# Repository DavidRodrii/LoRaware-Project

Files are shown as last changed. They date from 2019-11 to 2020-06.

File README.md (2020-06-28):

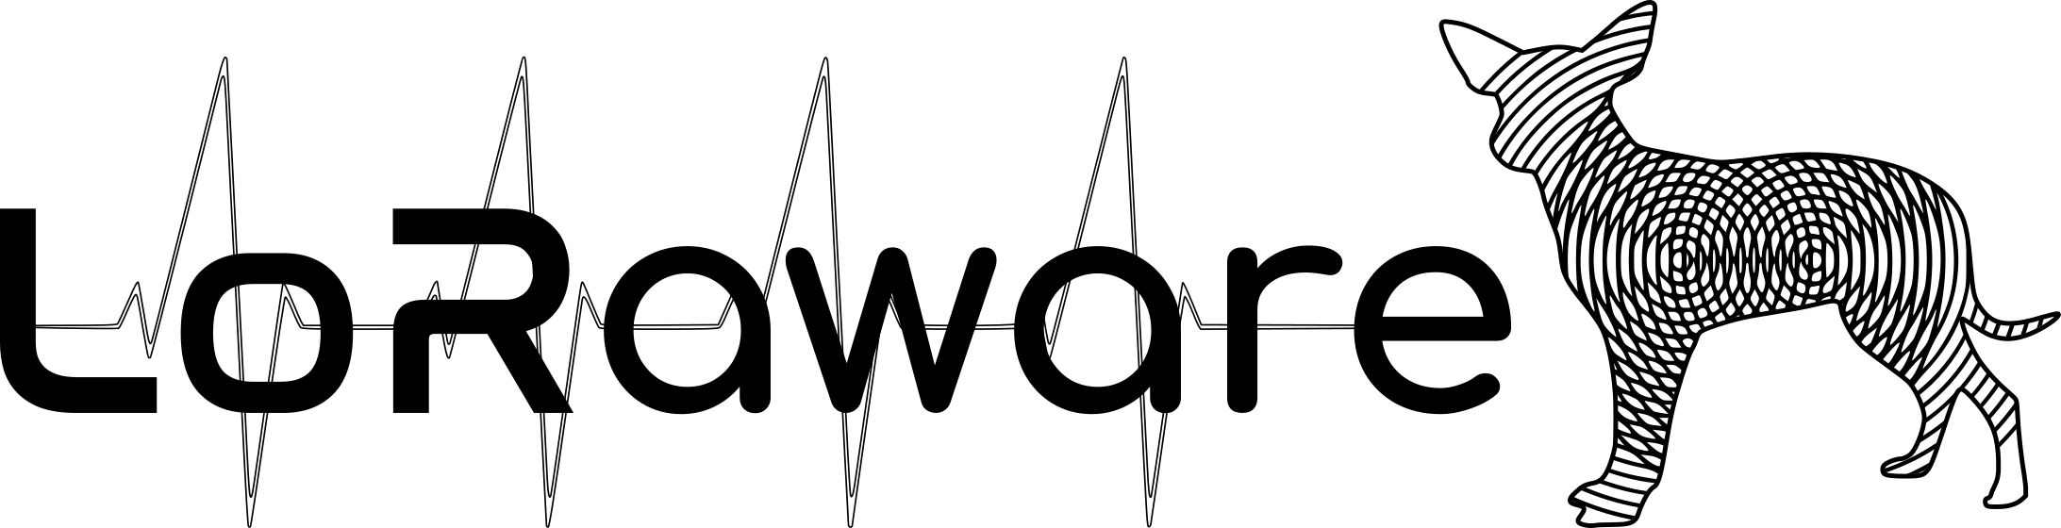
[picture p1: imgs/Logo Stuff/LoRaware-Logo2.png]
The LoRaware Project


### What is it?

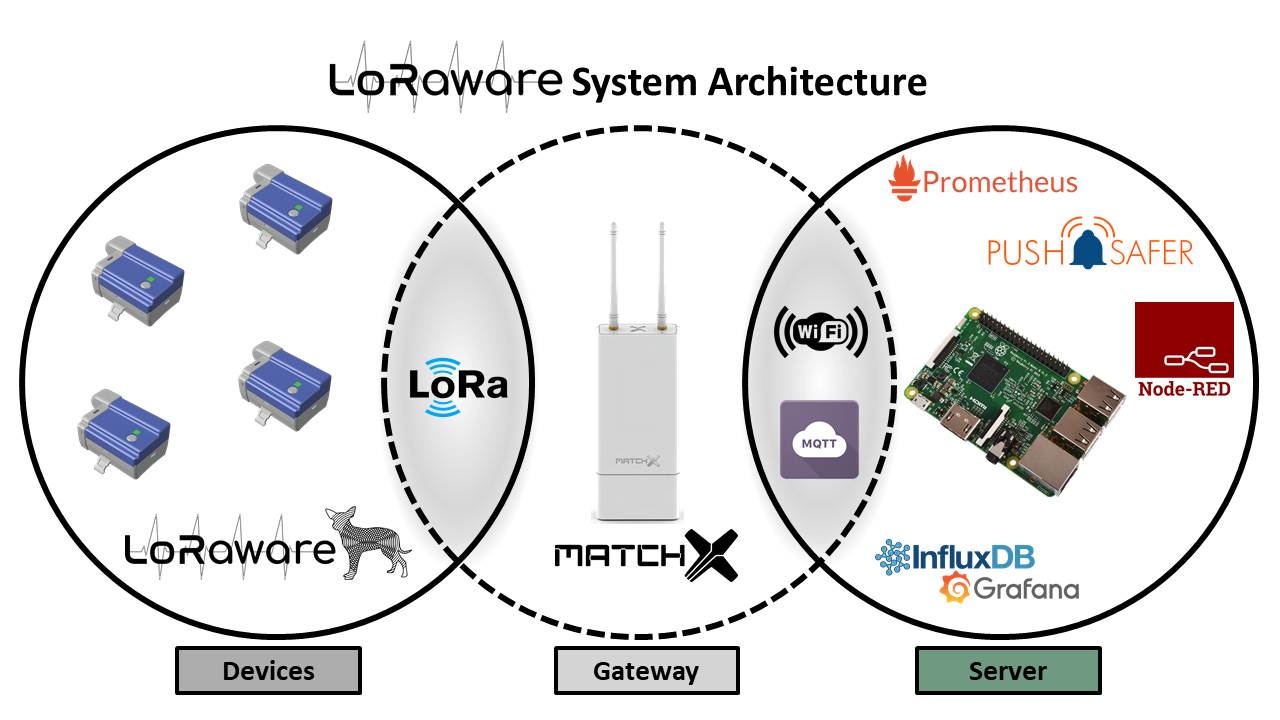
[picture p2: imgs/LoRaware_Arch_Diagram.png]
The LoRaware System Architecture


This capstone project represents the culmination of the Master of Science in Electrical Engineering with specialization in Wireless Communication program at National University. This project focused on the research and development of a wireless sensor network for use in the medical field pertaining to out-patient monitoring. The developed system's first deployment consisted of four wireless biometric devices transmitting communications over a Long-Range Wide Area Network (LoRaWAN). The observed biometric data was obtained by a combination of sampling, reading analog and digital voltage values, and conversions performed by each device’s processor, then transmitted to a centralized LoRaWAN Gateway, which was then parsed and forwarded to a network server via TCP/IP Stack to be stored and displayed by hosted services and applications; forming a lightweight and functional management platform. The project team developed and successfully tested the proposed LoRaware system throughout the course of a three-month duration.

Assembly of Snap-Fit Enclosure Shells

Enclosure Assembly

The sensor sets are portable and wrist-wearable and include sensors for biometric measurements, a ESP32 MCU, a Lithium Polymer battery, LoRa RF Modulation chipset and external antenna for data transmissions. All components fit in a low-profile enclosure.

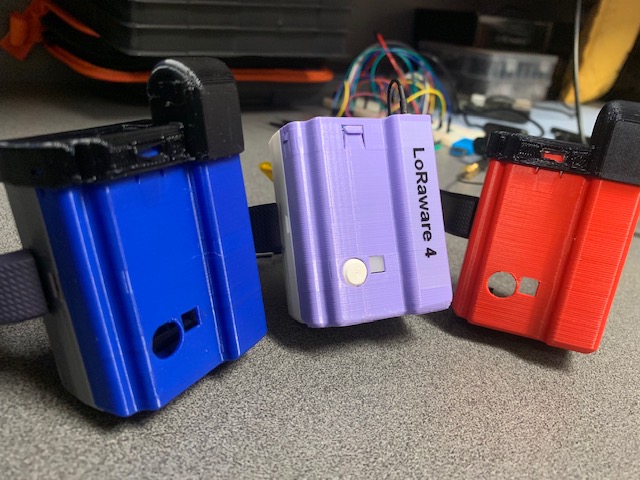
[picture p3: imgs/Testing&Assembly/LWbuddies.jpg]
Hmmmm...


<!--
Cutaway View
<img src="https://raw.githubusercontent.com/DavidRodrii/LoRaware-Project/master/imgs/lware-cutaway1.png" alt="Cutaway View" />
-->

Rendering of Full Assembly
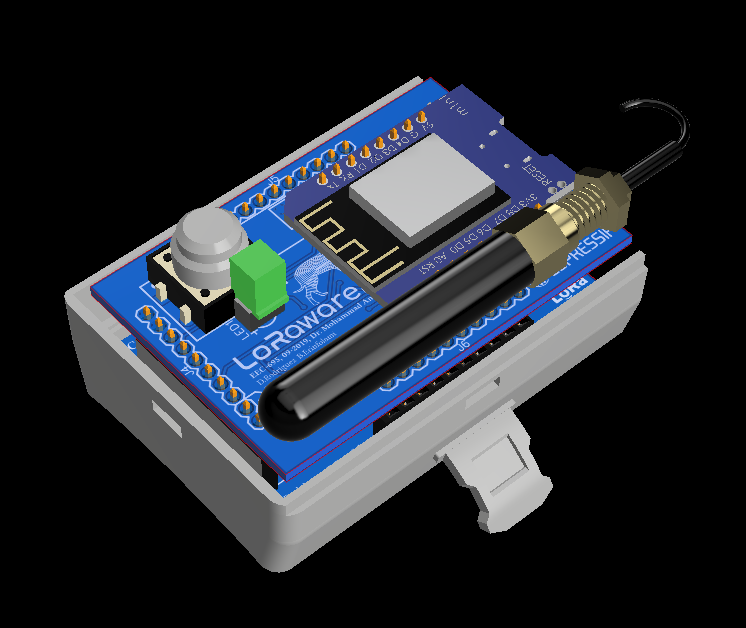
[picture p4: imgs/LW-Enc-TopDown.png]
Fully Assembly, wit da Top Down


### Use-case

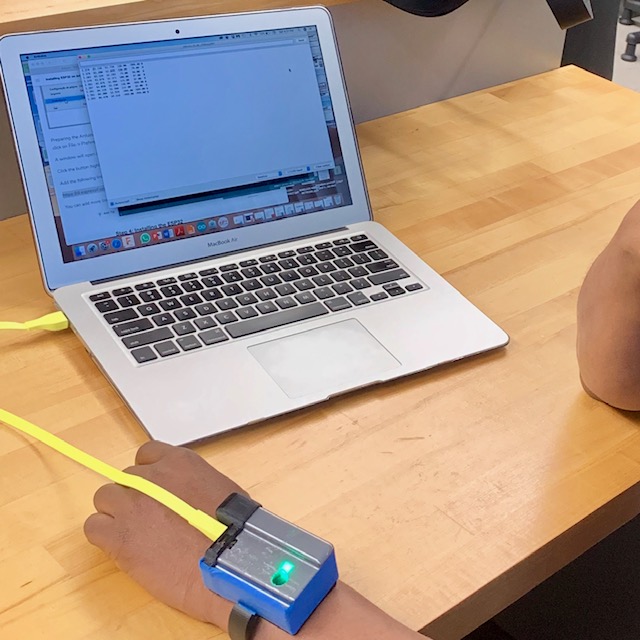
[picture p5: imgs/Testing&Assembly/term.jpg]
Debugging LoRaware Device


Biometric Monitoring

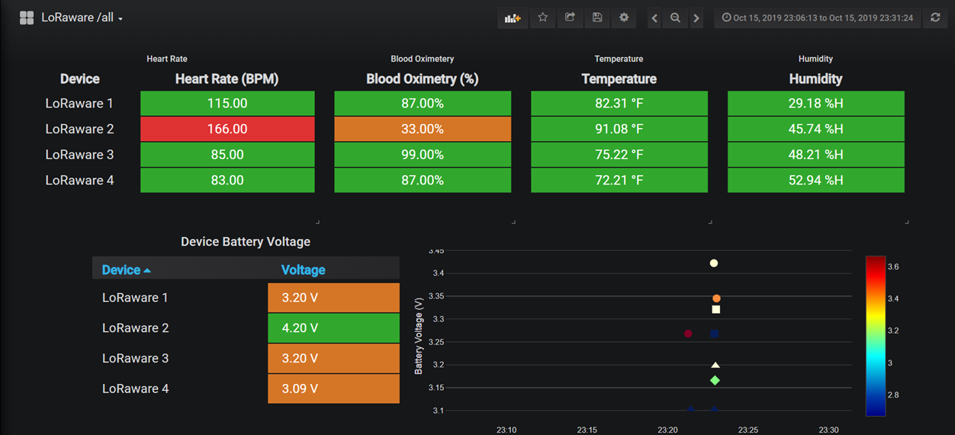
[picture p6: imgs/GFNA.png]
Monitoring Biometrics


<!-- Signal-to-Noise Ratio of Received LoRaWAN Packets
<img src="https://raw.githubusercontent.com/DavidRodrii/LoRaware-Project/master/imgs/LoRa_SNR.png" alt="SNR" />
-->

MQTT Data Flow Management topology in Node-Red
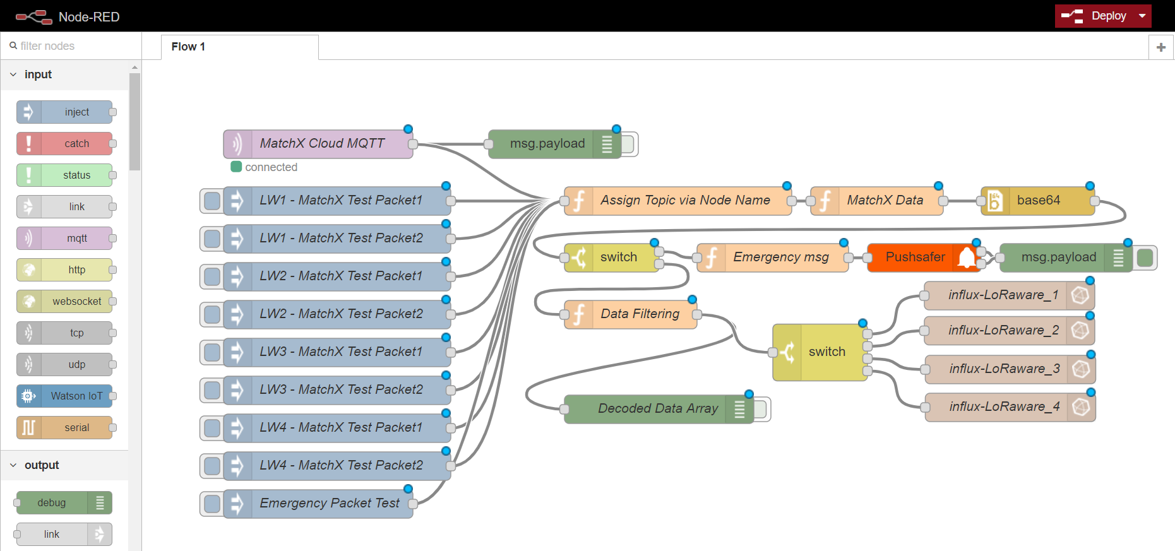
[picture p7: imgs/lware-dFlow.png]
Flow Control


LoRaware Automated Notification System with Pushsafer API
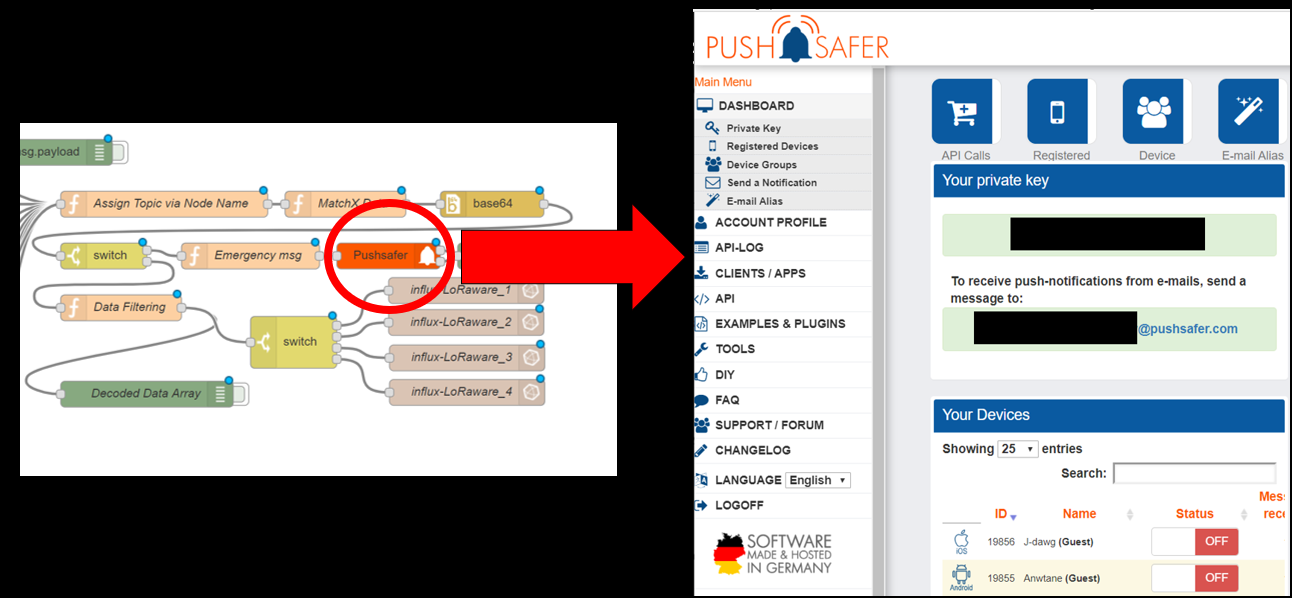
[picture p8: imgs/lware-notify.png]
Notify System


### Development

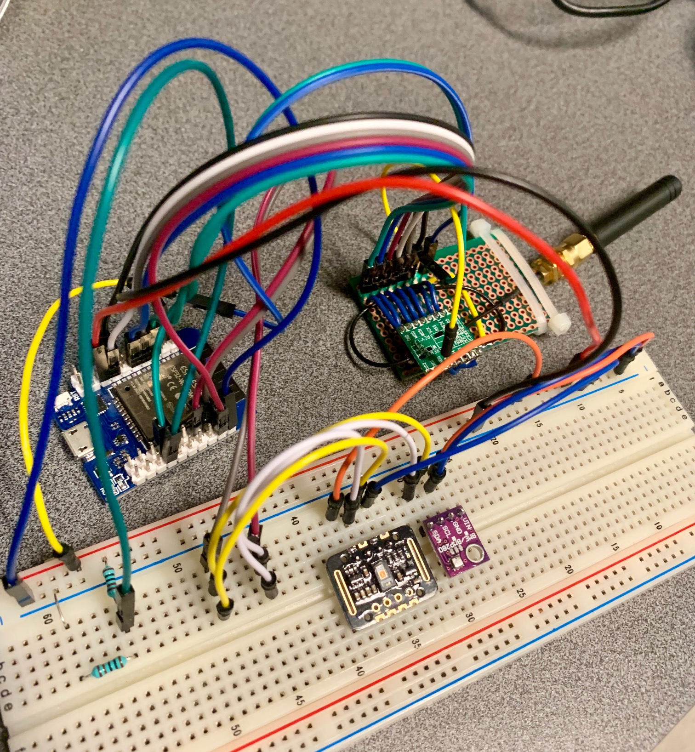
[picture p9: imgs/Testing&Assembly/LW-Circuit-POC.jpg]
LOL


LoRaware Prototype Schematic
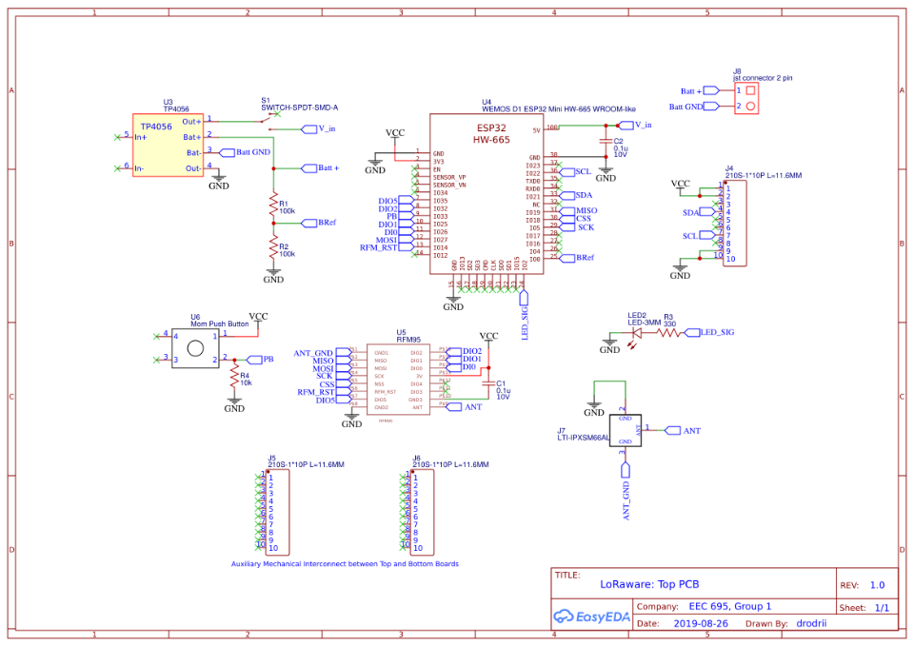
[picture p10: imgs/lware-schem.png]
LW Prototype Schematic


LoRaware PCB Assembly Concept
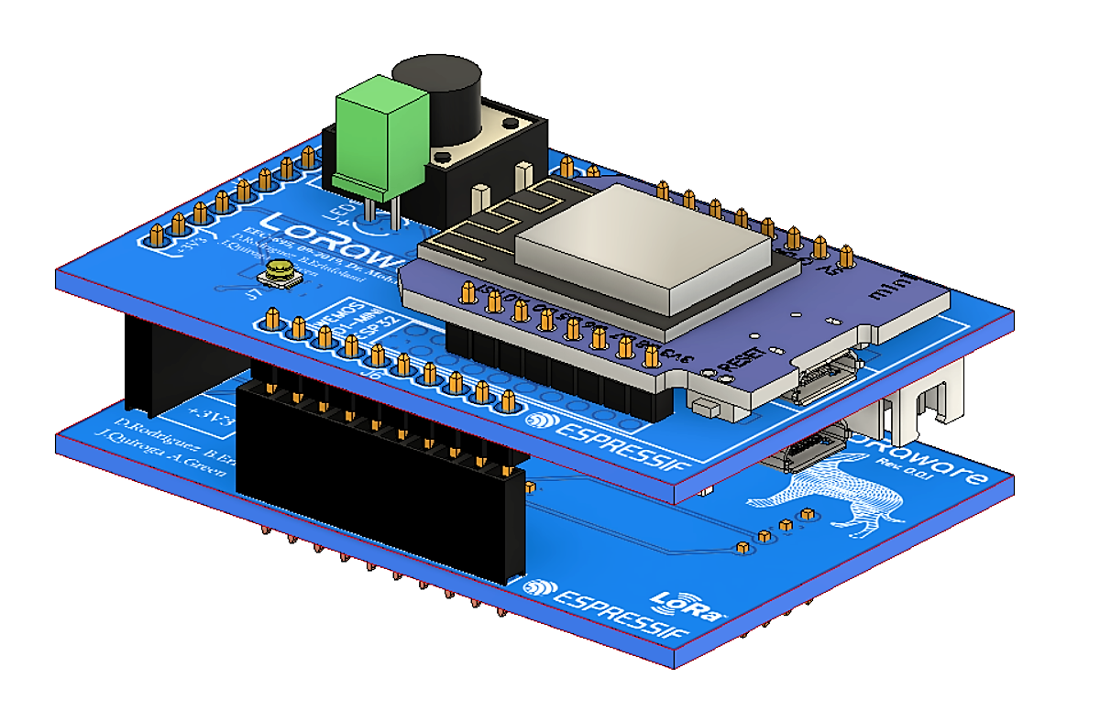
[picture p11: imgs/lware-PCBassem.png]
PCB Concept


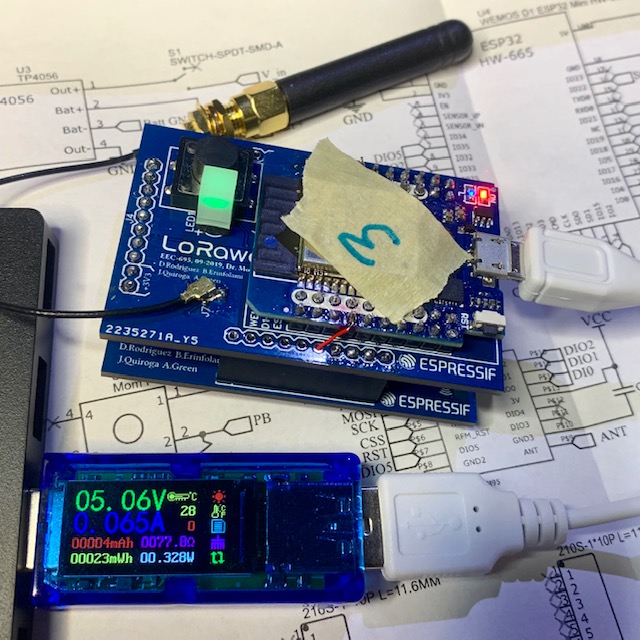
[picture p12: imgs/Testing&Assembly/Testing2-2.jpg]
LoRaware Device Power Measurements


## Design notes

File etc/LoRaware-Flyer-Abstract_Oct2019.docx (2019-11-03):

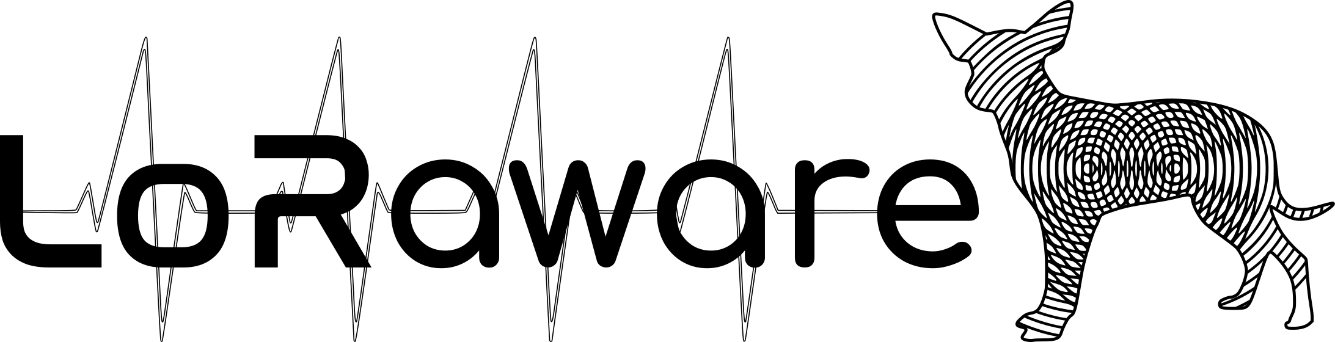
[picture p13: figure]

David Rodriguez, Jorge Quiroga, Antwane Green, Babatope Erinfolami

Each year, unmonitored hospital patients account for a significant percentage of preventable loss of life outside of the ICU. In an effort to address this problem surrounding the often overlooked out-patient and day-patient population within hospitals, LoRaware was developed in part by NU DOEC staff member, David Rodriguez, and fellow EEC capstone group members as a proof of concept for Long-Range (LoRa), Low-Power Wide Area Networking Technology (LPWAN) that will be demonstrated live in presentation. LoRaware is a wireless patient monitoring system comprised of multiple designed and built wearable prototype devices facilitated by a modern Internet of Things (IoT) Architecture and Multi-Network Topology in order to yield improvements in battery life, formfactor design, spectrum bandwidth allocation, secure data transfer, and ease of implementation over currently available wireless patient monitoring products.

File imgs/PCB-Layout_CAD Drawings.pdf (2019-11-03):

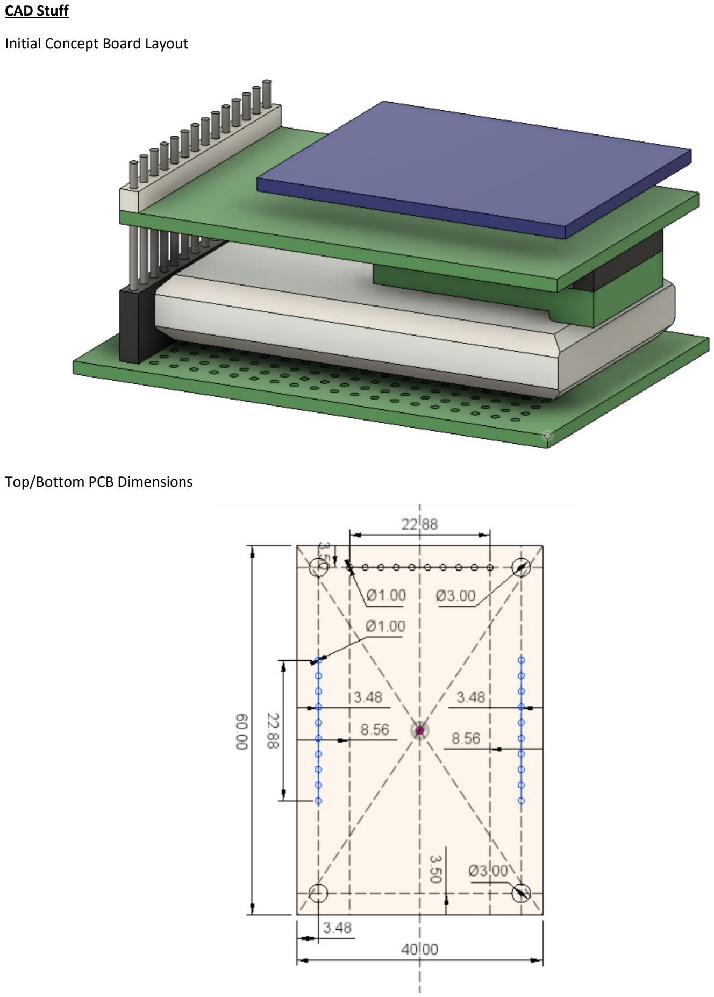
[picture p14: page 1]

CAD Stuff
Initial Concept Board Layout

Top/Bottom PCB Dimensions

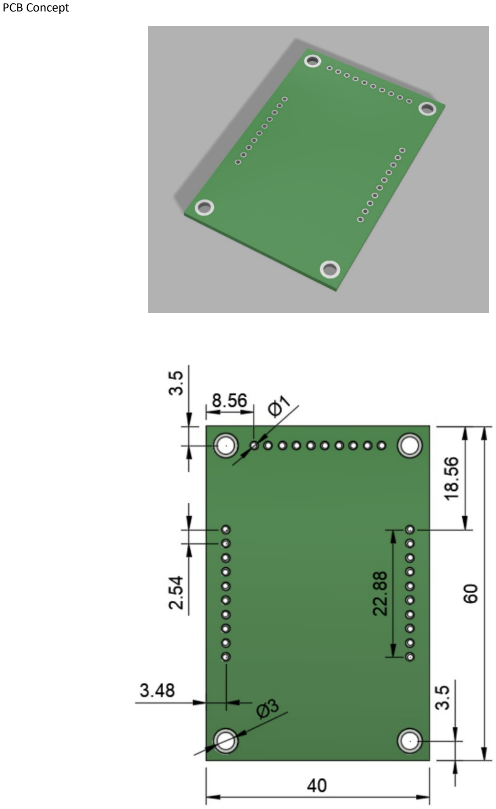
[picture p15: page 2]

PCB Concept

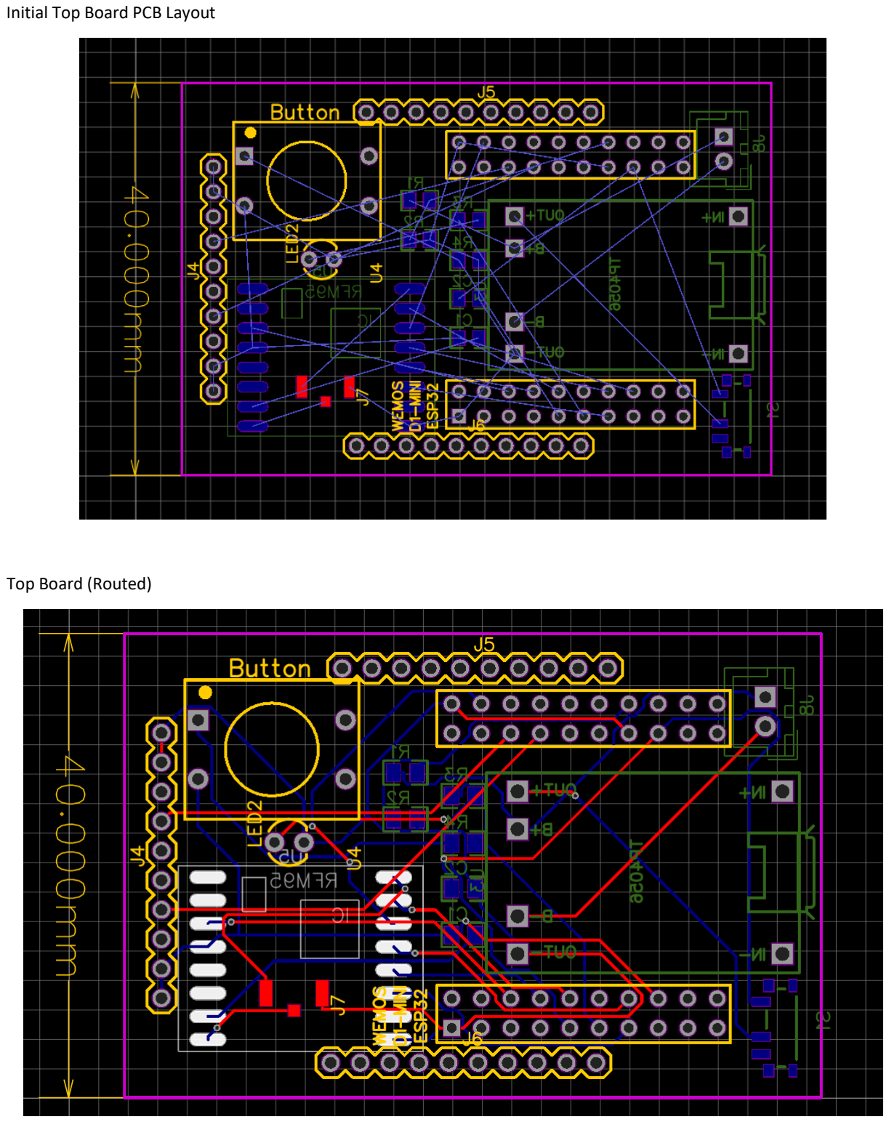
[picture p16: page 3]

Initial Top Board PCB Layout

Top Board (Routed)

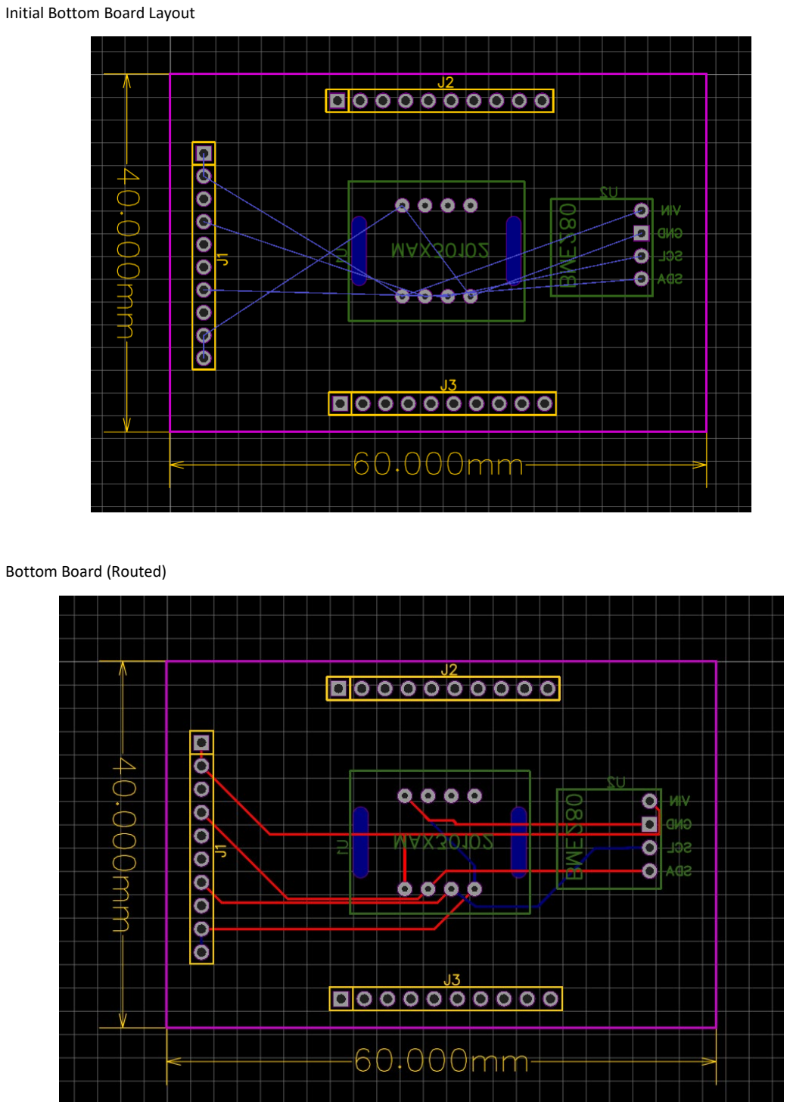
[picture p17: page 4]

Initial Bottom Board Layout

Bottom Board (Routed)

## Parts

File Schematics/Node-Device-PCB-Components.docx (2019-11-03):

CEE690 – Node Components

RFM95 - $8

https://github.com/SeeedDocument/RFM95-98_LoRa_Module/blob/master/RFM95_96_97_98_DataSheet.pdf

https://www.amazon.com/gp/product/B07KZPQ4GB/ref=ppx_yo_dt_b_search_asin_title?ie=UTF8&psc=1

BN-280 GPS Module - $10

http://surehobby.com/desc/HR/HR5512/BN_220_GPS_Antenna_datasheet.pdf

https://www.amazon.com/gp/product/B07TGJTCTB/ref=ppx_yo_dt_b_asin_title_o03_s00?ie=UTF8&psc=1

ESP32-WROOM-32D $3.80 (or ESP32 WeMos D1)

https://www.espressif.com/sites/default/files/documentation/esp32-wroom-32d_esp32-wroom-32u_datasheet_en.pdf

MAX30102 - $7.99

https://datasheets.maximintegrated.com/en/ds/MAX30102.pdf

https://www.amazon.com/gp/product/B07GGSM8SP/ref=ppx_yo_dt_b_asin_title_o00_s00?ie=UTF8&psc=1

BME280 - $6.44

https://cdn-shop.adafruit.com/datasheets/BST-BME280_DS001-10.pdf

TP4056 - $1.20

https://dlnmh9ip6v2uc.cloudfront.net/datasheets/Prototyping/TP4056.pdf

https://www.amazon.com/gp/product/B01DRT4PWY/ref=ppx_yo_dt_b_search_asin_title?ie=UTF8&psc=1

IPEX UFL connector - $1.66

https://www.amazon.com/gp/product/B071JNGHWQ/ref=ppx_yo_dt_b_asin_title_o00_s00?ie=UTF8&psc=1

LoRa antenna - $2.75

https://www.amazon.com/gp/product/B07LCKNN4H/ref=ppx_yo_dt_b_search_asin_title?ie=UTF8&psc=1

2000 mAh LiPo battery - $10.49

https://www.amazon.com/gp/product/B07BTV4J26/ref=ppx_yo_dt_b_search_asin_title?ie=UTF8&psc=1

Watch strap - $5

https://www.amazon.com/gp/product/B07BWGSMXS/ref=ppx_yo_dt_b_asin_title_o04_s00?ie=UTF8&psc=1

Digikey

SMT Slide Switch - $0.71 [10]

https://www.digikey.com/product-detail/en/nidec-copal-electronics/CUS-12TB/563-1102-1-ND/1124231

Green Diffused LED - $0.68 [10]

https://www.digikey.com/product-detail/en/sunled/XSDG23MB/1497-1042-ND/4745857

100k Ohm Resistors, 0805 SMT - $0.36 [15]

https://www.digikey.com/product-detail/en/panasonic-electronic-components/ERA-6AEB104V/P100KDACT-ND/1465995

10k Ohm Resistors, 0805 SMT - $0.10 [10]

https://www.digikey.com/product-detail/en/stackpole-electronics-inc/RNCP0805FTD10K0/RNCP0805FTD10K0CT-ND/2240601

330 Ohm Resistors, 0805 SMT - $0.10 [10]

https://www.digikey.com/product-detail/en/rohm-semiconductor/ESR10EZPJ331/RHM330KCT-ND/1763012

0.1 uF Capacitors, 0805 SMT - $0.66 [15]

https://www.digikey.com/product-detail/en/panasonic-electronic-components/ECP-U1C104MA5/PCF1126CT-ND/285453

Digikey Order Total: $25.22

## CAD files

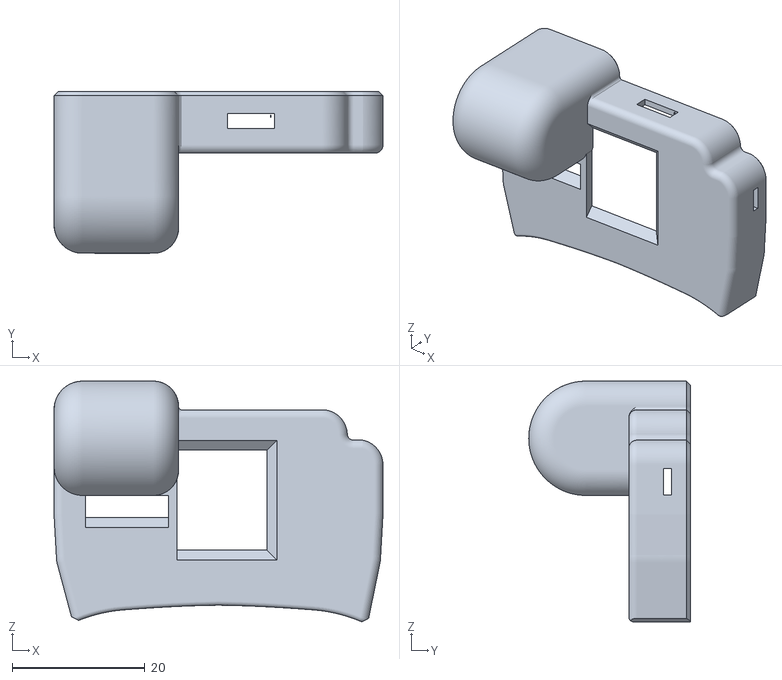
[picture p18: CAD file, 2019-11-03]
Enclosure .stl Files/EndCap - V2_Enclosure.stl
49.5 x 24.3 x 36.2

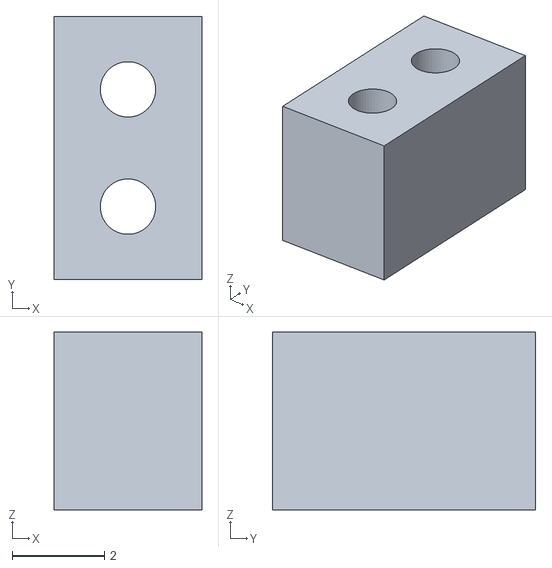
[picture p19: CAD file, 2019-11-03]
Enclosure .stl Files/V3_LED Spacer.stl
3.20 x 5.70 x 3.85

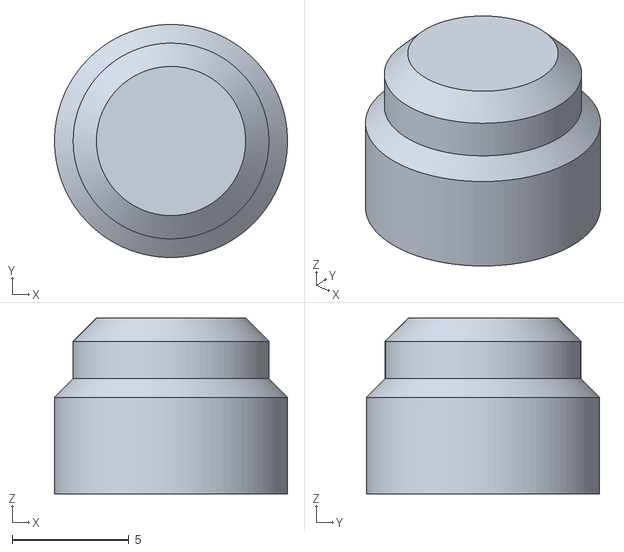
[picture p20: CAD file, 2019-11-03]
Enclosure .stl Files/V3_Button Cap.stl
10.00 x 10.00 x 7.55

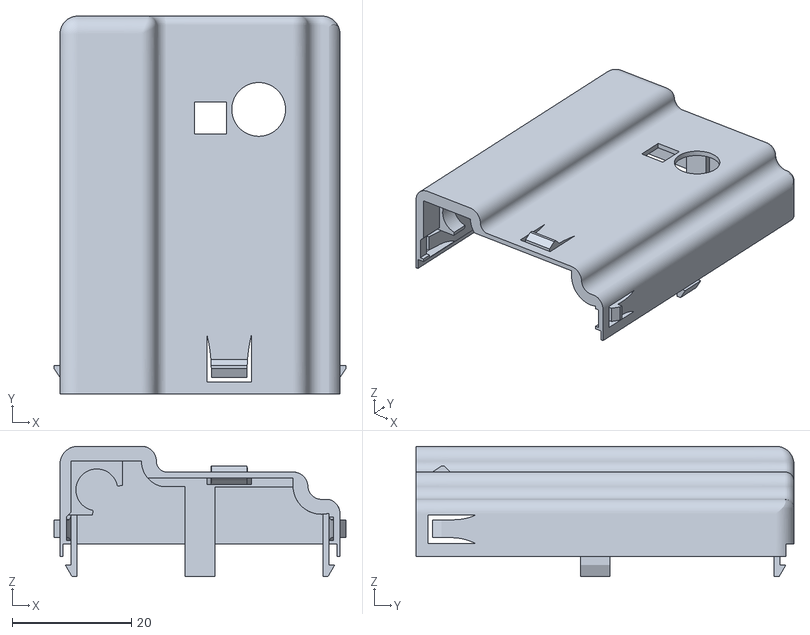
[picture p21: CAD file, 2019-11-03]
Enclosure .stl Files/V3_Top-Enclosure.stl
48.9 x 63.3 x 21.9

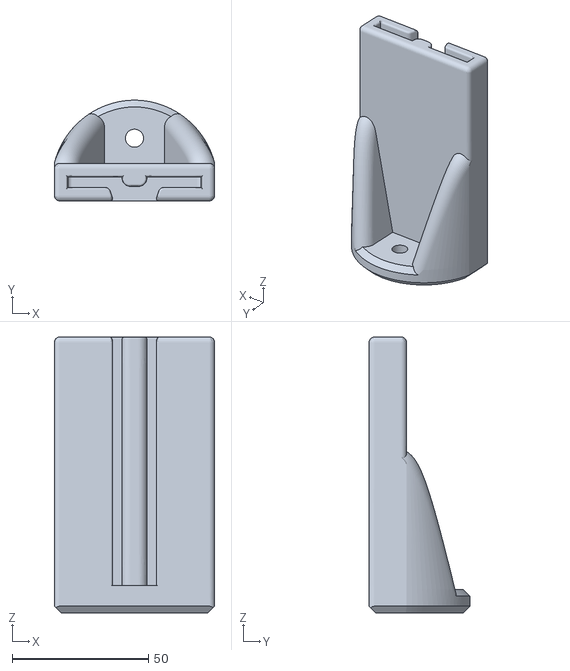
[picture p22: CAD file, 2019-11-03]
Enclosure .stl Files/MatchX Tripod Mount_V1.stl
59.0 x 37.1 x 101.5

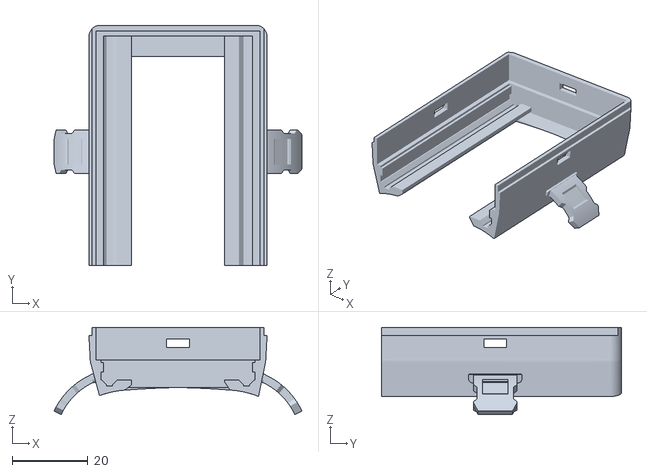
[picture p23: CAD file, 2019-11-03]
Enclosure .stl Files/Bottom - Enclosure.stl
65.3 x 63.3 x 22.9

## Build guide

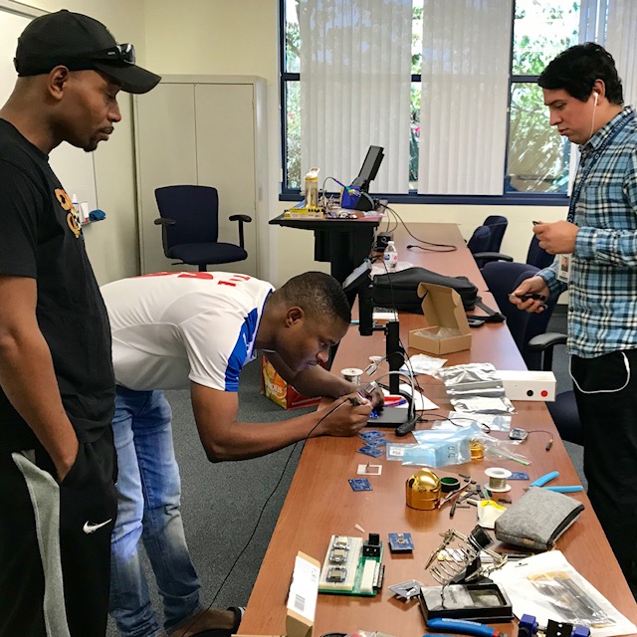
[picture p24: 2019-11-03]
imgs/Testing&Assembly/Solderstructions.jpg

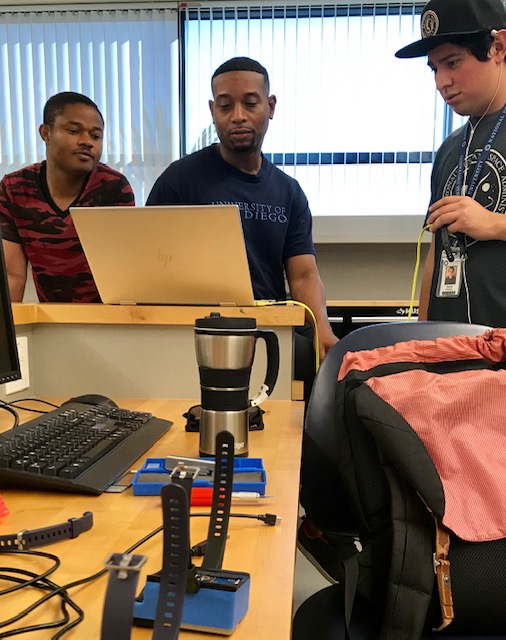
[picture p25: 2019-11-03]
imgs/Testing&Assembly/DataInspect.jpg

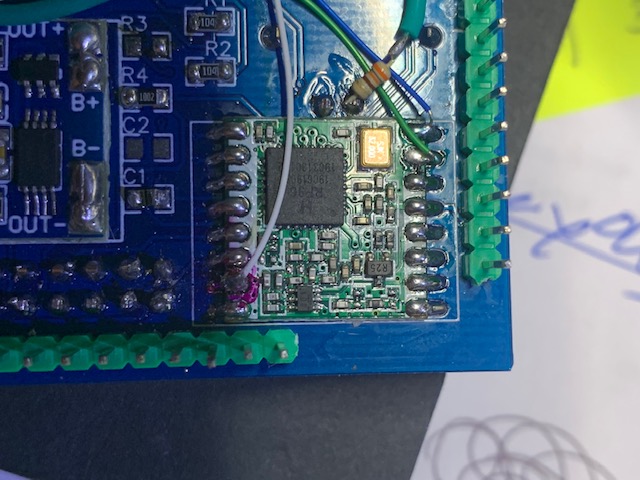
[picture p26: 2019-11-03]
imgs/Testing&Assembly/bodge.jpg

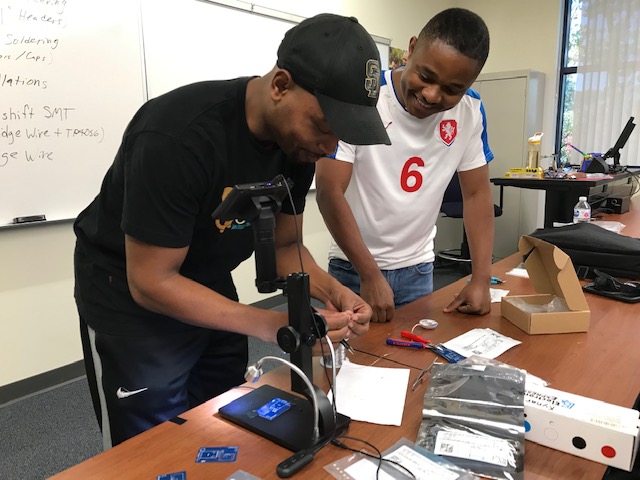
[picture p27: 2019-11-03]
imgs/Testing&Assembly/AssemblyTime.JPG

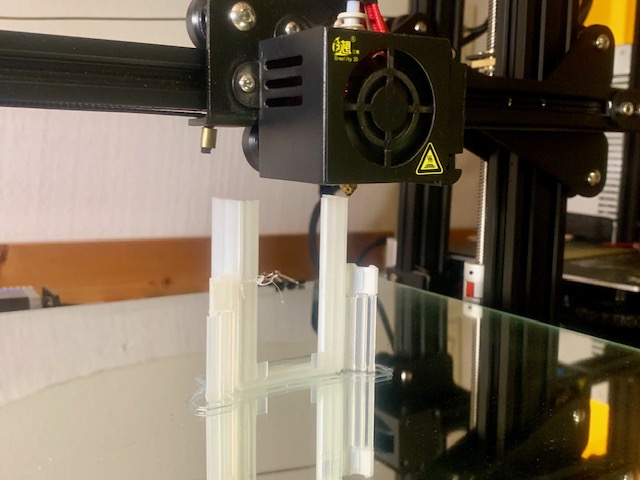
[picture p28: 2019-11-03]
imgs/Testing&Assembly/Printing.jpg

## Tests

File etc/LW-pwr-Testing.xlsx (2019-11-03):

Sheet: Sheet1
LoRaware Device Testing: Power Measurements
Li-Po Battery Capacity (mAh): |  |  | 2000
Target Battery Life (hrs): |  |  | 16
USB Power Meter 1 (Blue)
Device | Current Draw (mA) | Power (W) | Battery Life (hrs)
LoRaware_1 | 66.0 | 0.333 | 30.30
LoRaware_2 | 63.0 | 0.319 | 31.75
LoRaware_3 | 60.0 | 0.303 | 33.33
LoRaware_4 | 58.0 | 0.298 | 34.48
Average Battery Life (hrs): |  |  | 32.47
Average Percent Improvement (%): |  |  | 102.91
USB Power Meter 2 (Black)
Device | Current Draw (mA) | Power (W) | Battery Life (hrs)
LoRaware_1 | 50.0 | 0.253 | 40.0
LoRaware_2 | 50.0 | 0.253 | 40.0
LoRaware_3 | 50.0 | 0.253 | 40.0
LoRaware_4 | 40.0 | 0.202 | 50.0
Average Battery Life (hrs): |  |  | 42.5
Average Percent Improvement (%): |  |  | 165.6
Overall Average Battery Life (hrs): |  |  | 37.48
Overall Average Percent Improvement (%): |  |  | 134.27

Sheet: Sheet2
LoRaware Device Testing: Power Measurements
Li-Po Battery Capacity (mAh): | 2000
Target Battery Life (hrs): | 16
Consolidated Results
Overall Average Battery Life (hrs): | 37.48
Overall Average Percent Improvement (%): | 134.27

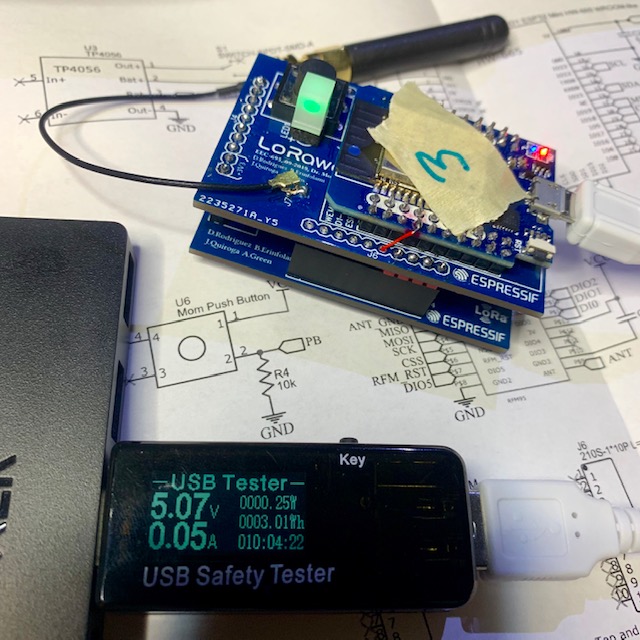
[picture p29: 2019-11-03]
imgs/Testing&Assembly/Testing2-1.jpg

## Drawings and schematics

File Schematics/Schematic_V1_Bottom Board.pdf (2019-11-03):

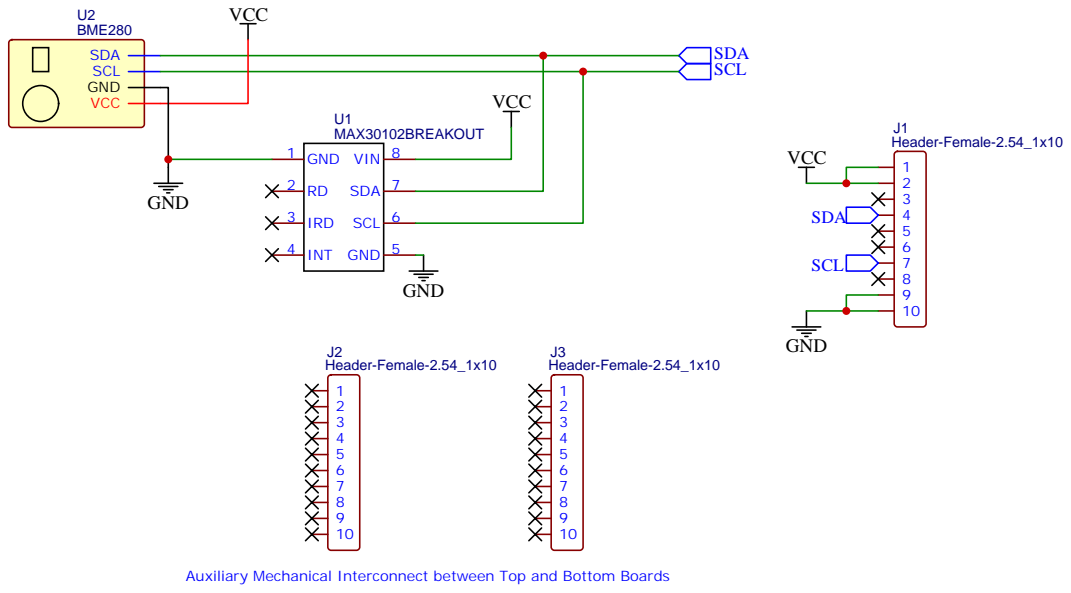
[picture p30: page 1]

Auxiliary Mechanical Interconnect between Top and Bottom Boards

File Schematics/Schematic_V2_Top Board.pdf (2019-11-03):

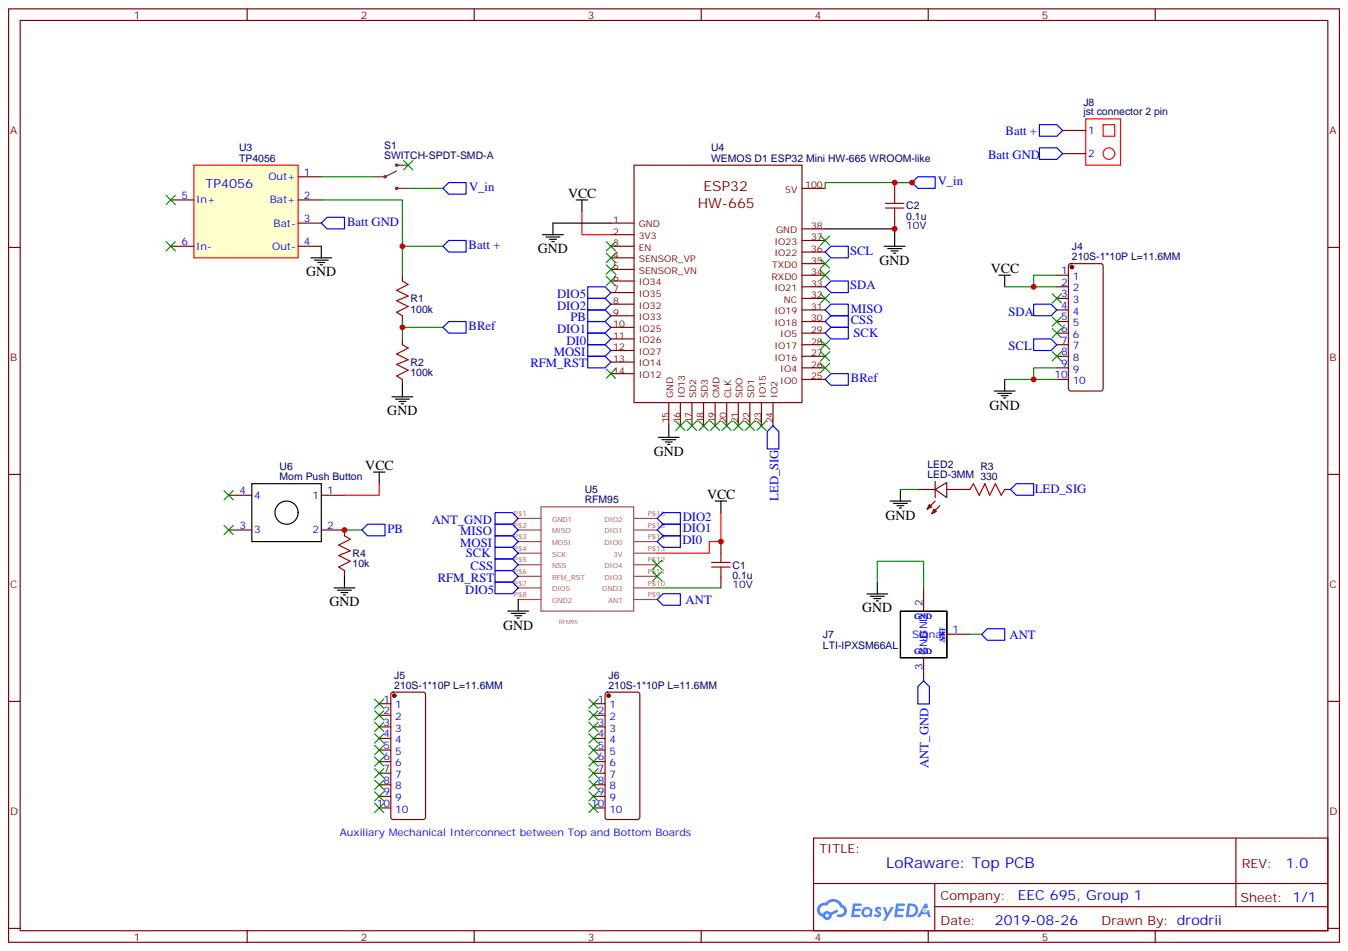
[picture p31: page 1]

Auxiliary Mechanical Interconnect between Top and Bottom Boards

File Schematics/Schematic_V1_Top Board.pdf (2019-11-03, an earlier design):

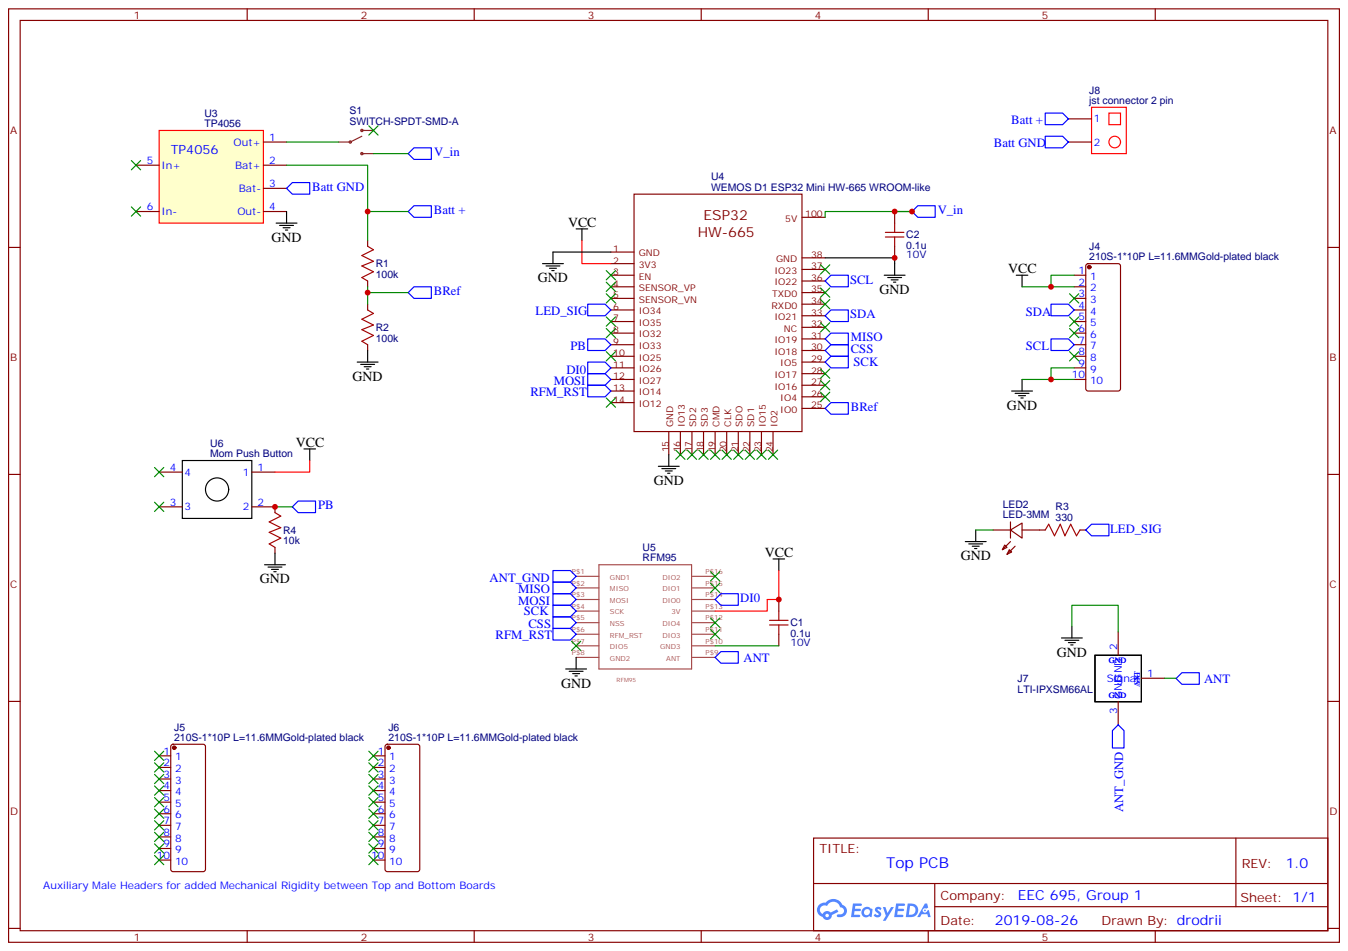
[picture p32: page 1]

Auxiliary Male Headers for added Mechanical Rigidity between Top and Bottom Boards

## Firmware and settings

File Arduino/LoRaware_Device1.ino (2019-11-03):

/**
 *  LoRaware Rev.6
 *      Author: David Rodriguez
 *      September 2019
 *  
 *  For US915MHz, Requires
 *  Beelan LoRaWAN Library: https://github.com/BeelanMX/Beelan-LoRaWAN
 *  
 *  Other Required Libraries
 *  ESP32_AnalogWrite: https://github.com/ERROPiX/ESP32_AnalogWrite
 *  Sparkfun_MAX3010x_Sensor_Library: https://github.com/sparkfun/SparkFun_MAX3010x_Sensor_Library
 *  Adafruit_BME280_Library: https://github.com/adafruit/Adafruit_BME280_Library
 *  
 *  LoRaware Device #1 
 */
#include <lorawan.h>
#include <SPI.h>
#include <Wire.h>
#include "MAX30105.h"
#include <Adafruit_Sensor.h>
#include <Adafruit_BME280.h>
#include "heartRate.h"
#include "spo2_algorithm.h"
#include <analogWrite.h>
Adafruit_BME280 bme;
MAX30105 particleSensor;
uint32_t irBuffer[100]; //infrared LED sensor data
uint32_t redBuffer[100];  //red LED sensor data
int32_t bufferLength; //data length
int32_t spo2; //SPO2 value
int8_t validSPO2; //indicator to show if the SPO2 calculation is valid
int32_t heartRate; //heart rate value
int8_t validHeartRate; //indicator to show if the heart rate calculation is valid
byte pulseLED = 34; //Must be on PWM pin
byte readLED = 2; //Blinks with each data read
byte battPin = 0; //Battery Voltage Pin
byte button = 33; //Push Button Pin
//ABP Credentials - FOR Device: LoRaware_1
const char *devAddr = "00000000"; 
const char *nwkSKey = "00000000000000000000000000000000";
const char *appSKey = "00000000000000000000000000000000";
#define MAX_BRIGHTNESS 255
#define SS 18
#define MISO 19
#define MOSI 27
#define SCK 5
unsigned long previousMillis = 0;  // will store last time message sent
int countHR = 0; // MAX30102 HR Error Counter
int countO2 = 0; // MAX30102 HR Error Counter
int wearState = 0; // Default Wear State Enabled
int dbgState = 0; // Default Debugging Disabled
char myStr[50];
char myStrCB[26];
char myStrVB[26];
char myStrT[26];
char myStrH[26];
char myStrHR[26];
char myStrO2[26];
char payload[255];
char emergencyPayload[255];
char outStr[255];
byte recvStatus = 0;
bool eState = false;
const sRFM_pins RFM_pins = {
  .CS = 18,
  .RST = 14,
  .DIO0 = 26,
  .DIO1 = 25,
  .DIO2 = 32,
  .DIO5 = 35,
};

void LEDbreathe() {
  // Breathes Green LED with Sinusoidal PWM Function
  for (int i = 0; i < 360; i++) {
    analogWrite(readLED, (sin(i * 0.0174533) + 1) * (127/16));
    delay(6);
} // End of void LEDbreathe()

void LoRaware_norm() {
  // LoRaware Normal Operation
  LEDbreathe();
  particleSensor.wakeUp();
  bufferLength = 100; //buffer length of 100 stores 4 seconds of samples running at 25 sps
  for (byte i = 0 ; i < bufferLength ; i++)
  {
    while (particleSensor.available() == false) //do we have new data?
      particleSensor.check(); //Check the sensor for new data

    if (eState == true) {
      break;
    }
    else {
     redBuffer[i] = particleSensor.getRed();
     irBuffer[i] = particleSensor.getIR();
     particleSensor.nextSample();
    }    
  }
  maxim_heart_rate_and_oxygen_saturation(irBuffer, bufferLength, redBuffer, &spo2, &validSPO2, &heartRate, &validHeartRate);
  float measuredvbat = analogRead(battPin);
  float battV;
  battV = (((measuredvbat)*(2.1) / (4096)))*2;
  dtostrf(battV,6, 3, myStrVB);
  dtostrf((bme.readTemperature()*(1.8) + 32),6, 3, myStrT);
  dtostrf(bme.readHumidity(),6, 3, myStrH);
  dtostrf(heartRate,6, 2, myStrHR);
  dtostrf(spo2,6, 2, myStrO2);  
  String str;
  str = (String(myStrVB) +","+ String(myStrT) +","+ String(myStrH) +","+ String(myStrHR) +","+ String(myStrO2));
  unsigned int str_len = 37;
  str.toCharArray(payload,str_len); 
  Serial.println(payload);
  // LoRaWAN Data Send Uplink to Gateway
  lora.sendUplink(payload, strlen(payload), 0); // 0 = LoRaWAN UNCONFIRMED Message Type
  analogWrite(readLED,0);
  particleSensor.shutDown();
  delay(5000);
  recvStatus = lora.readData(outStr);
  if(recvStatus) {
  }
  // Check Lora RX
  lora.update();
  particleSensor.wakeUp();
} // End of void LoRaware_norm()

void emergencyPush() {
  analogWrite(readLED,250);
  static unsigned long last_interrupt_time = 0;
  unsigned long interrupt_time = millis();
  // Disregard Interrupts faster than 200 ms
  if (interrupt_time - last_interrupt_time > 200){
    eState = !eState;
  }
  last_interrupt_time = interrupt_time;
} // End of void emergencyPush()

void sendEmergencyLoRa() {
  analogWrite(readLED,250);
  // LoRaWAN Emergency Message Payload
  particleSensor.shutDown();
  analogWrite(readLED,250);
  delay(300);
  String emergencyStr;
  emergencyStr = (String(0) +","+ String(0) +","+ String(0) +","+ String(0) +","+ String(0));
  Serial.println("Sending Emergency msg");
  unsigned int str_len = 37;
  emergencyStr.toCharArray(emergencyPayload,str_len); 
  Serial.println(emergencyPayload);
  delay(100);    
  // LoRaWAN Data Send Uplink to Gateway
  lora.sendUplink(emergencyPayload, strlen(emergencyPayload), 0); // 0 = LoRaWAN UNCONFIRMED Message Type
  // Check Lora RX
  lora.update();
  eState = !eState;
  analogWrite(readLED,0);    
} // End of void sendEmergencyLoRa()

void setup() {
  Serial.begin(115200);
  pinMode(pulseLED, OUTPUT);
  pinMode(readLED, OUTPUT);
  pinMode(battPin, INPUT);
  pinMode(button, INPUT_PULLUP);
  attachInterrupt(digitalPinToInterrupt(button), emergencyPush, HIGH); // Button Pin as Interrupt Pin
  if (!particleSensor.begin(Wire, I2C_SPEED_FAST)) //Use default I2C port, 400kHz speed
  {
    Serial.println("MAX30105 was not found. Please check wiring/power. ");
    while (1);
  }
  if (!bme.begin(0x76)) {
    Serial.println("Could not find a valid BME280 sensor, check wiring!");
    while (1);
  }
  SPI.begin(SCK,MISO,MOSI,SS);
  if(!lora.init()){
    Serial.println("RFM95 not detected");
    delay(5000);
    yield();
    return;
  }
  // LoRaWAN Class
  lora.setDeviceClass(CLASS_A);
  // Data Rate
  lora.setDataRate(SF8BW125);
  // Channel Set to Random
  lora.setChannel(MULTI);
  // ABP Key and DevAddress
  lora.setNwkSKey(nwkSKey);
  lora.setAppSKey(appSKey);
  lora.setDevAddr(devAddr);
  byte ledBrightness = 45; //Options: 0=Off to 255=50mA
  byte sampleAverage = 16; //Options: 1, 2, 4, 8, 16, 32
  byte ledMode = 2; //Options: 1 = Red only, 2 = Red + IR, 3 = Red + IR + Green
  byte sampleRate = 400; //Options: 50, 100, 200, 400, 800, 1000, 1600, 3200
  int pulseWidth = 118; //Options: 69, 118, 215, 411
  int adcRange = 8192; //Options: 2048, 4096, 8192, 16384 
  particleSensor.setup(ledBrightness, sampleAverage, ledMode, sampleRate, pulseWidth, adcRange); // MAX30102 Sensor Configuration
} // End of void setup

void loop() {
  start:
  if (eState == true) {
    sendEmergencyLoRa();
    goto start;
  }
  else {
    eState = false;
    //LEDbreathe();
    LoRaware_norm();
    goto start;
  }
} // End of void loop

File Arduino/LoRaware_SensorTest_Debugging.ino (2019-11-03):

// LoRaware Debugging and Testing: Sensor Measurements

#include <lorawan.h>
#include <SPI.h>
#include <Wire.h>
#include "MAX30105.h"
#include <Adafruit_Sensor.h>
#include <Adafruit_BME280.h>
#include "heartRate.h"
#include "spo2_algorithm.h"
#include <analogWrite.h>
Adafruit_BME280 bme;
MAX30105 particleSensor;
uint32_t irBuffer[100]; //infrared LED sensor data
uint32_t redBuffer[100];  //red LED sensor data
int32_t bufferLength; //data length
int32_t spo2; //SPO2 value
int8_t validSPO2; //indicator to show if the SPO2 calculation is valid
int32_t heartRate; //heart rate value
int8_t validHeartRate; //indicator to show if the heart rate calculation is valid
byte pulseLED = 34; //Must be on PWM pin
byte readLED = 2; //Blinks with each data read
byte battPin = 0; //Battery Voltage Pin
byte button = 33; //Push Button Pin
//ABP Credentials - FOR Device: LoRaware_1
const char *devAddr = "00000000";
const char *nwkSKey = "00000000000000000000000000000000";
const char *appSKey = "00000000000000000000000000000000";
#define MAX_BRIGHTNESS 255
#define SS 18
#define MISO 19
#define MOSI 27
#define SCK 5
unsigned long previousMillis = 0;  // will store last time message sent
int countHR = 0; // MAX30102 HR Error Counter
int countO2 = 0; // MAX30102 HR Error Counter
int wearState = 0; // Default Wear State Enabled
int dbgState = 0; // TESTING Default Debugging Disabled
char myStr[50];
char myStrCB[26];
char myStrVB[26];
char myStrT[26];
char myStrH[26];
char myStrHR[26];
char myStrO2[26];
char payload[255];
char emergencyPayload[64];
char outStr[255];
byte recvStatus = 0;
boolean buttonActive = false;
boolean longPressActive = false;
long buttonTimer = 0;
long longPressTime = 3000; // ms
int inputVarInt;
const sRFM_pins RFM_pins = {
  .CS = 18,
  .RST = 14,
  .DIO0 = 26,
  .DIO1 = 25,
  .DIO2 = 32,
  .DIO5 = 35,
};

void LEDbreathe() {
  for (int i = 0; i < 360; i++) {
    analogWrite(readLED, (sin(i * 0.0174533) + 1) * (127/2));
    delay(3);
  }
  for (int i = 360; i > 0; i--) {
    analogWrite(readLED, (sin(i * 0.0174533) + 1) * (127/2));
    delay(3);
  }
  analogWrite(readLED,0);
}

void LoRawareDebugMode() {
  LEDbreathe();
  analogWrite(readLED,0);
  dbgState = 1;
  bufferLength = 75; //buffer length of 100 stores 4 seconds of samples running at 25sps
  //read the first 100 samples, and determine the signal range
  for (byte i = 0 ; i < bufferLength ; i++)
  {
    while (particleSensor.available() == false)
      particleSensor.check(); //Check the sensor for new data
    redBuffer[i] = particleSensor.getRed();
    irBuffer[i] = particleSensor.getIR();
    particleSensor.nextSample();
  }
  //calculate heart rate and SpO2 after first 100 samples (first 4 seconds of samples)
  maxim_heart_rate_and_oxygen_saturation(irBuffer, bufferLength, redBuffer, &spo2, &validSPO2, &heartRate, &validHeartRate);
    for (byte i = 25; i < 100; i++)
    {
      redBuffer[i - 25] = redBuffer[i];
      irBuffer[i - 25] = irBuffer[i];
    }
    for (byte i = 75; i < 100; i++)
    {
      while (particleSensor.available() == false)
        particleSensor.check(); //Check the sensor for new data

      digitalWrite(readLED, !digitalRead(readLED)); //Blink onboard LED with every data read

      redBuffer[i] = particleSensor.getRed();
      irBuffer[i] = particleSensor.getIR();
      digitalWrite(readLED, LOW);
      particleSensor.nextSample();
    }
    maxim_heart_rate_and_oxygen_saturation(irBuffer, bufferLength, redBuffer, &spo2, &validSPO2, &heartRate, &validHeartRate);
  float measuredvbat = analogRead(battPin);
  float battV;
  battV = (((measuredvbat)*(2.1) / (4096)))*2;
  dtostrf(battV,6, 3, myStrVB);
  dtostrf((bme.readTemperature()*(1.8) + 32),6, 3, myStrT);
  dtostrf(bme.readHumidity(),6, 3, myStrH);
  dtostrf(heartRate,6, 2, myStrHR);
  dtostrf(spo2,6, 2, myStrO2);
  
  // WearState Detection (wearState = 0 Indicates device currently being worn)
      if (validHeartRate == 0){
        countHR = countHR+1;
        }
      else {
        countHR = 0; 
      }
      //if (myStrO2 == "-999.00"){
      if (validSPO2 == 0){
        countO2 = countO2+1;
        }
      else {
        countO2 = 0;
      }
  if ((countHR > 1) && (countO2 > 2)){
    wearState = 1; 
    //Serial.println("Patient Not Detected");
    } // Indicates Device is NOT currently being worn
  else {
    wearState = 0;
    }
  String str;
  str = (String(myStrVB) +","+ String(myStrT) +","+ String(myStrH) +","+ String(myStrHR) +","+ String(myStrO2)+","+ String(wearState));
  particleSensor.shutDown();
      if (inputVarInt == 1) {
        Serial.println(String(myStrVB) +"\t"+ String(myStrT) +"\t"+ String(myStrH) +"\t"+ String(myStrHR) +"\t"+ String(myStrO2)+"\t"+ String(wearState));
      }
      else if (inputVarInt ==2) {
        Serial.println(myStrVB);
      }
      else if (inputVarInt == 3) {
        Serial.println(myStrT);
      }
      else if (inputVarInt == 4) {
        Serial.println(myStrH);
      }
      else if (inputVarInt == 5) {
        if (myStrHR != "-999.00") {
          Serial.println(myStrHR); }
        else {
        }
      }
      else if (inputVarInt == 6) {
        if (myStrHR != "-999.00") {
          Serial.println(myStrO2); }
        else {
        }
      }
      if (inputVarInt == 7) {
        if (wearState == 0) {
          Serial.print("countHR: ");
          Serial.print(countHR);
          Serial.print("\t");
          Serial.print("countO2: ");
          Serial.print(countO2);
          Serial.print("\t");
          Serial.println("Device ON Patient"); }
        else {
          Serial.print("countHR: ");
          Serial.print(countHR);
          Serial.print("\t");
          Serial.print("countO2: ");
          Serial.print(countO2);
          Serial.print("\t");
          Serial.println("Device OFF Patient"); }
      }
  delay(1000);
  particleSensor.wakeUp();
} // End of Void LoRawareDebugMode()


void modeChange() {
  if (digitalRead(button) == LOW) {
    if (buttonActive == false) {
      buttonActive = true;
      buttonTimer = millis();
    }
    if ((millis() - buttonTimer > longPressTime) && (longPressActive == false)) {
      longPressActive = true;
    }
  }
  else {
    if (buttonActive == true) {
      if (longPressActive == true) {
        longPressActive = false;
        dbgState = !dbgState;
      } 
      else {
        String emergencyStr;
        emergencyStr = (String(0) +","+ String(0) +","+ String(0) +","+ String(0) +","+ String(0)+","+ String(0));
        Serial.println(emergencyStr);
        unsigned int str_len = 14;
        emergencyStr.toCharArray(emergencyPayload,str_len); 
        Serial.println(emergencyPayload);
        // Flash Green Square LED
        digitalWrite(pulseLED,HIGH);
        delay(500);
        digitalWrite(pulseLED,LOW);    
      }
      buttonActive = false;
      }
  }  
} // End of void ModeChange
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

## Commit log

2019-11-03 Arduino codes directory & libraries added
2019-11-03 CAD & .stl stuff added
    [Bottom - Enclosure.stl, EndCap - V2_Enclosure.stl, LW-pwr-Testing.xlsx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]
2019-11-03 PCB stuffs & Raspi dependencies added
    [Bottom+Board_V1.pcbdoc, Top-Board_V1.pcbdoc]
2019-11-03 Schematics added
    [Bottom+Board_V1.schdoc, Top+Board_V1.schdoc, Top+Board_V2.schdoc]
